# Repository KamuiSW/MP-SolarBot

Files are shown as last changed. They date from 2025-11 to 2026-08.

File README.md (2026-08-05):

# Solar Panel Cleaning Robot

This is the code and hardware files for our 6VWO profielwerkstuk. The project is about a small robot that can map a solar panel, plan a path over it, and detect dirty spots.

## Parts of the project

### 1. Firmware
Language: C++ <br>
Hardware: Raspberry Pi <br><br>
What it does:<br>
Motor control <br>
Edge detection with sensors<br>
Mapping the panel<br>
Navigation over the mapped area<br><br>
Compilation:<br>
    ```g++ main.cpp mapping.cpp navigation.cpp executor.cpp stains.cpp stain_planner.cpp -o robot_core -lwiringPi -std=c++17
    ```

### 2. Web interface and simulation
Backend: Python<br>
Frontend: HTML5<br><br>
The web interface shows the robot position, the path, and detected stains. There is also a Python simulation so we can test the logic without always using the real robot.<br>

## Simulation

1.  Install dependencies:
    ```bash
    pip install fastapi uvicorn websockets
    ```

2.  Run the server:
    ```bash
    python Software\src\Simulation\server.py
    ```

3.  Open the UI:
    Open `http://localhost:8000` in your web browser.

4.  Start the simulation:
Click "Start Simulation".<br>

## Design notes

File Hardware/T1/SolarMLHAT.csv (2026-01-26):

Female pin header 2x20 2.54mm THT vertical
Pin header 1x4 2.54mm THT vertical
Pin header 1x4 2.54mm THT vertical
Pin header 1x3 2.54mm THT vertical
Pin header 1x3 2.54mm THT vertical
Pin header 1x4 2.54mm THT vertical HC-SR04
Pin header 1x4 2.54mm THT vertical HC-SR04
Screw terminal block 2 pin 5.0mm THT
Electrolytic capacitor 2200uF 16V radial 5mm
Ceramic capacitor 100nF 1206 X7R 25V
Resistor 10k ohm 1206 1%
Resistor 10k ohm 1206 1%
Resistor 20k ohm 1206 1%
Resistor 20k ohm 1206 1%

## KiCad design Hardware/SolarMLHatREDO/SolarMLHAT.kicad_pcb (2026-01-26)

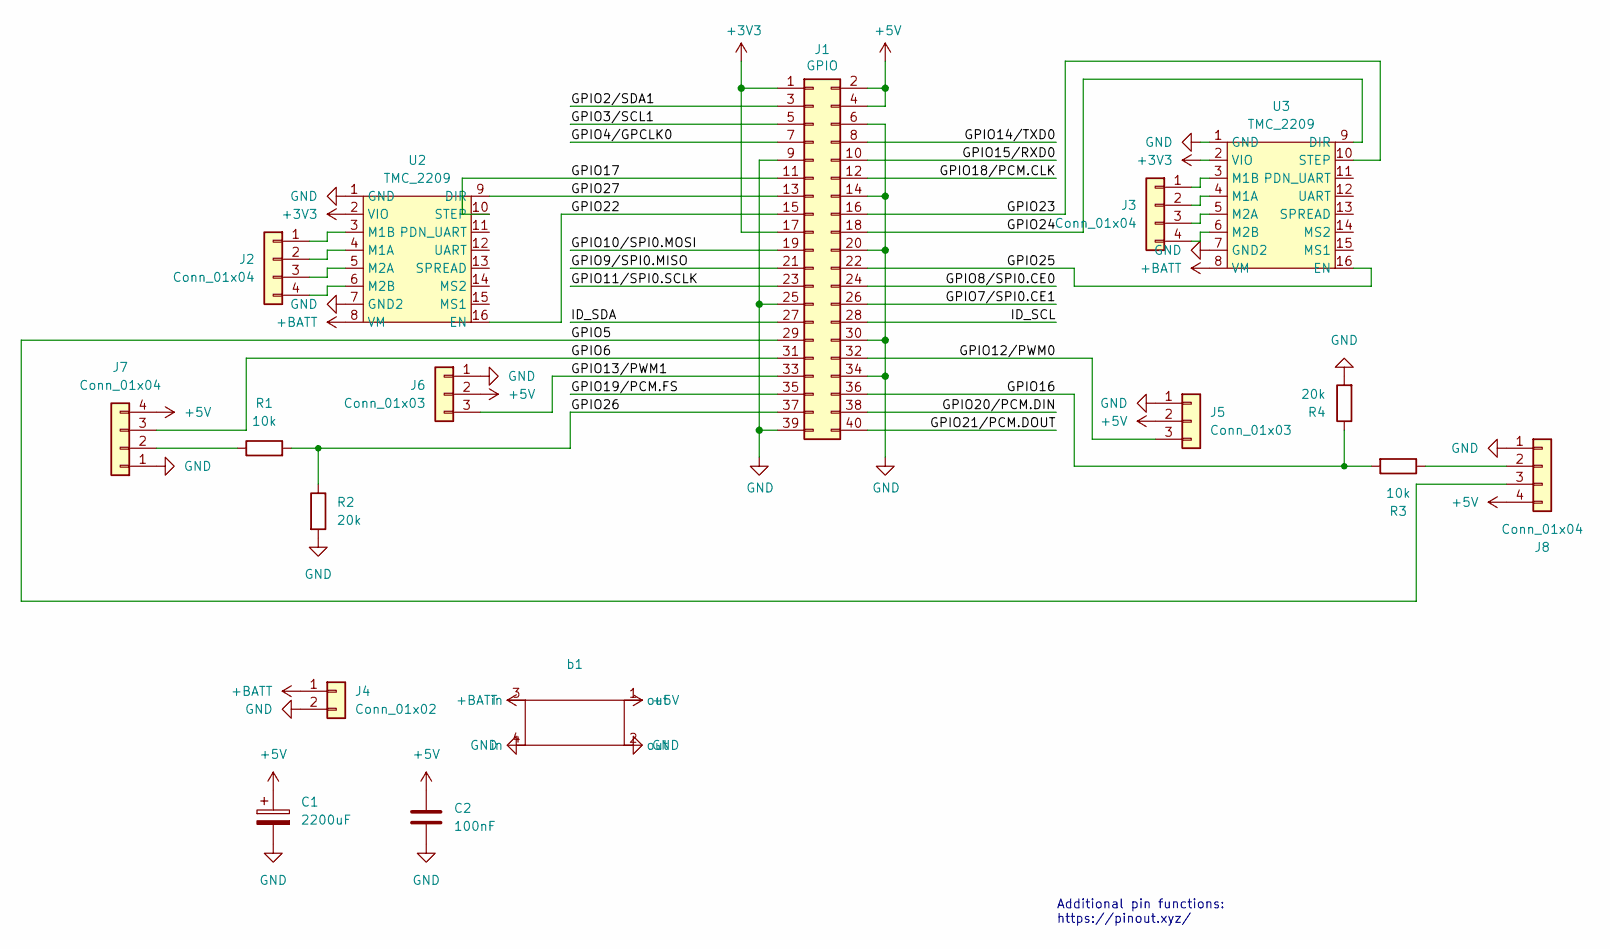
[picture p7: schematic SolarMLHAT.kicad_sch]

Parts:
C1: 2200uF; CP_Radial_D10.0mm_P5.00mm
C2: 100nF; C_1206_3216Metric_Pad1.33x1.80mm_HandSolder
J1: GPIO; PinSocket_2x20_P2.54mm_Vertical
J2, J3: Conn_01x04; JST_PH_B4B-PH-K_1x04_P2.00mm_Vertical
J4: Conn_01x02; TerminalBlock_MaiXu_MX126-5.0-02P_1x02_P5.00mm
J5, J6: Conn_01x03; PinHeader_1x03_P2.54mm_Vertical
J7, J8: Conn_01x04; PinHeader_1x04_P2.54mm_Vertical
R1, R3: 10k; R_1206_3216Metric_Pad1.30x1.75mm_HandSolder
R2, R4: 20k; R_1206_3216Metric_Pad1.30x1.75mm_HandSolder
U2, U3: TMC_2209; TMC_2209_v985
b1: XL4015 5A SizeM

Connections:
+3V3: J1.1, J1.17, U2.2 (VIO), U3.2 (VIO)
+5V: C1.1, C2.1, J1.2, J1.4, J5.2, J6.2, J7.4, J8.4, b1.1 (out)
+BATT: J4.1, U2.8 (VM), U3.8 (VM), b1.3 (in)
/GPIO2/SDA1: J1.3
/GPIO3/SCL1: J1.5
/GPIO4/GPCLK0: J1.7
/GPIO5: J1.29, J8.3
/GPIO6: J1.31, J7.3
/GPIO7/SPI0.CE1: J1.26
/GPIO8/SPI0.CE0: J1.24
/GPIO9/SPI0.MISO: J1.21
/GPIO10/SPI0.MOSI: J1.19
/GPIO11/SPI0.SCLK: J1.23
/GPIO12/PWM0: J1.32, J5.3
/GPIO13/PWM1: J1.33, J6.3
/GPIO14/TXD0: J1.8
/GPIO15/RXD0: J1.10
/GPIO16: J1.36, R3.2, R4.1
/GPIO17: J1.11, U2.10 (STEP)
/GPIO18/PCM.CLK: J1.12
/GPIO19/PCM.FS: J1.35
/GPIO20/PCM.DIN: J1.38
/GPIO21/PCM.DOUT: J1.40
/GPIO22: J1.15, U2.16 (EN)
/GPIO23: J1.16, U3.10 (STEP)
/GPIO24: J1.18, U3.9 (DIR)
/GPIO25: J1.22, U3.16 (EN)
/GPIO26: J1.37, R1.2, R2.1
/GPIO27: J1.13, U2.9 (DIR)
/ID_SCL: J1.28
/ID_SDA: J1.27
GND: C1.2, C2.2, J1.6, J1.9, J1.14, J1.20, J1.25, J1.30, J1.34, J1.39, J4.2, J5.1, J6.1, J7.1, J8.1, R2.2, R4.2, U2.1 (GND), U2.7 (GND2), U3.1 (GND), U3.7 (GND2), b1.2 (out), b1.4 (in)
unnamed: J2.1, U2.3 (M1B)
unnamed: J2.2, U2.4 (M1A)
unnamed: J2.3, U2.5 (M2A)
unnamed: J2.4, U2.6 (M2B)
unnamed: J3.1, U3.3 (M1B)
unnamed: J3.2, U3.4 (M1A)
unnamed: J3.3, U3.5 (M2A)
unnamed: J3.4, U3.6 (M2B)
unnamed: J7.2, R1.1
unnamed: J8.2, R3.1

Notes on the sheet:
Additional pin functions: https://pinout.xyz/

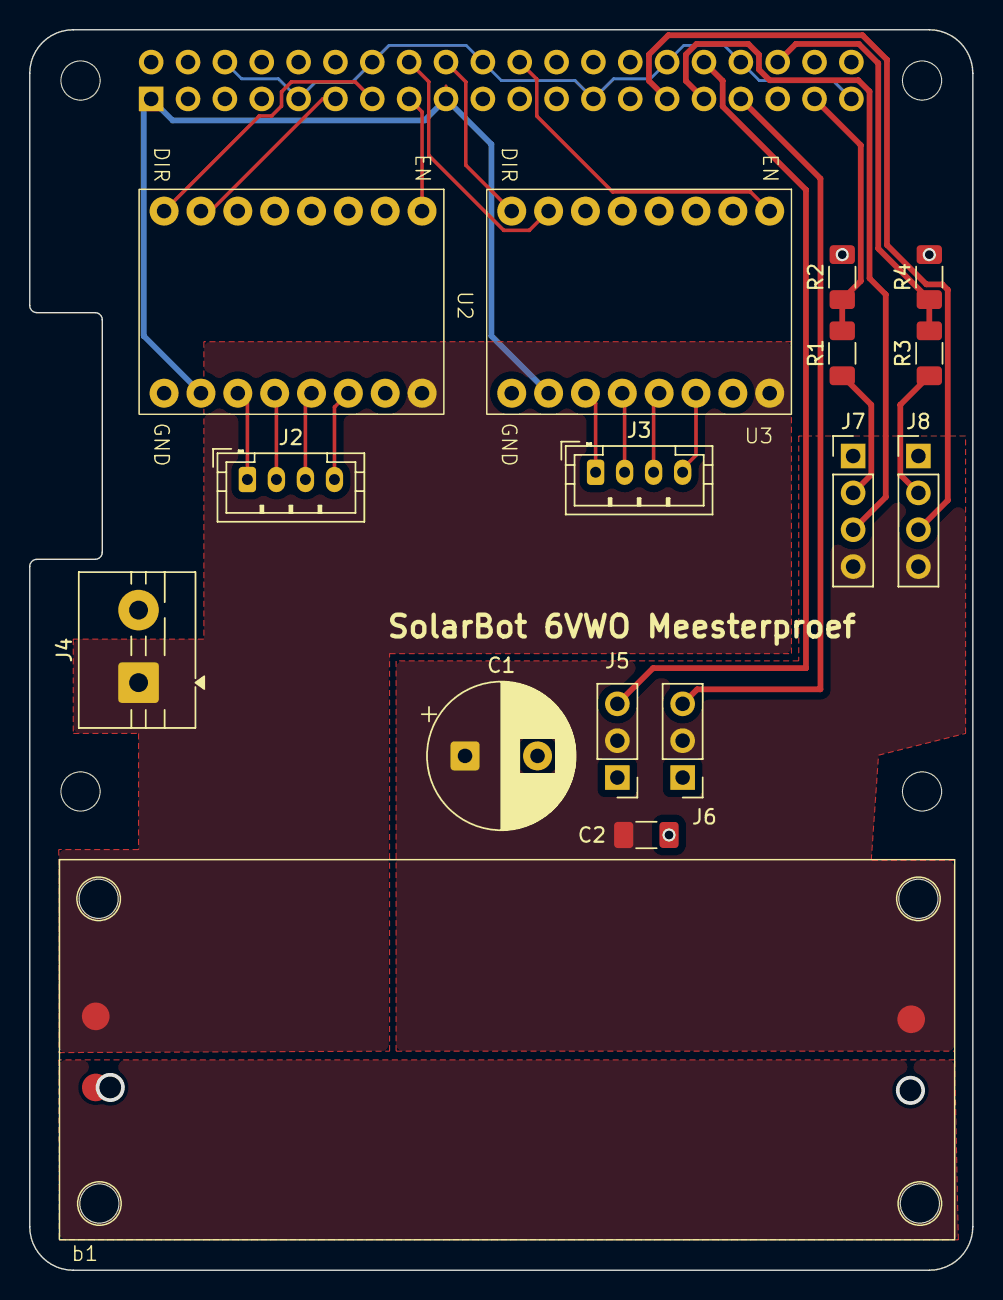
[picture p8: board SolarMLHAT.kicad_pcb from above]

Board: 2 copper layers, 65.0 x 85.5 mm, 21 parts (1 on the bottom side), 26 nets.

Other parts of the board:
MH1, MH2, MH3, MH4: MountingHole_2.7mm_M2.5

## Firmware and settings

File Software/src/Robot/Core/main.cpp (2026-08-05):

#include <atomic>
#include <iostream>
#include <string>
#include <thread>
#include <vector>

#include "config.h"
#include "executor.h"
#include "mapping.h"
#include "navigation.h"

// The Python server sends one JSON command per line, for example:
// {"cmd": "start_mapping"}

void printJsonStatus(const std::string &status, const std::string &msg = "") {
  std::cout << "{\"type\":\"status\", \"status\": \"" << status
            << "\", \"msg\": \"" << msg << "\"}" << std::endl;
}

int main() {
  printJsonStatus("IDLE", "Robot Core Ready");

  std::string line;
  while (std::getline(std::cin, line)) {
    if (line.find("start_mapping") != std::string::npos) {
      printJsonStatus("BUSY", "Starting Mapping...");
      if (runMapping()) {
        printJsonStatus("IDLE", "Mapping Complete");
      } else {
        printJsonStatus("ERROR", "Mapping Failed");
      }
    } else if (line.find("start_navigation") != std::string::npos) {
      printJsonStatus("BUSY", "Starting Navigation...");
      if (runNavigation()) {
        printJsonStatus("IDLE", "Navigation Planning Complete");
      } else {
        printJsonStatus("ERROR", "Navigation Planning Failed");
      }
    } else if (line.find("start_execution") != std::string::npos) {
      printJsonStatus("BUSY", "Starting Execution...");
      if (runExecuteNavigation()) {
        printJsonStatus("IDLE", "Execution Complete");
      } else {
        printJsonStatus("ERROR", "Execution Failed");
      }
      printJsonStatus("ERROR", "Execution Failed");
    }
  }
  else if (line.find("stop") != std::string::npos) {
    printJsonStatus("STOPPED", "Stopping...");
    // For now stop just exits the loop.
    break;
  }
}

return 0;
}

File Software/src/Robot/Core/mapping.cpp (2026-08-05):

#ifndef MOCK_HARDWARE
#include <wiringPi.h>
#endif

#include <algorithm>
#include <chrono>
#include <fstream>
#include <iostream>
#include <set>
#include <thread>
#include <vector>

#include "config.h"
#include "mapping.h"

class Stepper {
public:
  int stepPin, dirPin, enPin;
  bool forwardLevel;

  Stepper(int step, int dir, int en, bool fwdLevel)
      : stepPin(step), dirPin(dir), enPin(en), forwardLevel(fwdLevel) {}

  void begin() {
    pinMode(stepPin, OUTPUT);
    pinMode(dirPin, OUTPUT);
    pinMode(enPin, OUTPUT);
    digitalWrite(enPin, LOW);
    digitalWrite(stepPin, LOW);
    digitalWrite(dirPin, forwardLevel ? HIGH : LOW);
  }

  void enable(bool on) { digitalWrite(enPin, on ? LOW : HIGH); }

  void setForward(bool forward) {
    bool lvl = forward ? forwardLevel : !forwardLevel;
    digitalWrite(dirPin, lvl ? HIGH : LOW);
  }

  void stepOnce() {
    digitalWrite(stepPin, HIGH);
    delayMicroseconds(STEP_PULSE_US);
    digitalWrite(stepPin, LOW);
  }
};

class DifferentialDrive {
public:
  Stepper left;
  Stepper right;

  DifferentialDrive(Stepper l, Stepper r) : left(l), right(r) {}

  void begin() {
    left.begin();
    right.begin();
    left.enable(true);
    right.enable(true);
  }

  void stop() {
    left.enable(false);
    right.enable(false);
  }

  void forwardCell() {
    left.setForward(true);
    right.setForward(true);
    for (int i = 0; i < STEPS_PER_CELL; i++) {
      left.stepOnce();
      right.stepOnce();
      delayMicroseconds(STEP_DELAY_US);
    }
  }

  void turnRight90() {
    left.setForward(true);
    right.setForward(false);
    for (int i = 0; i < STEPS_PER_90_TURN; i++) {
      left.stepOnce();
      right.stepOnce();
      delayMicroseconds(STEP_DELAY_US);
    }
  }

  void turnLeft90() {
    left.setForward(false);
    right.setForward(true);
    for (int i = 0; i < STEPS_PER_90_TURN; i++) {
      left.stepOnce();
      right.stepOnce();
      delayMicroseconds(STEP_DELAY_US);
    }
  }
};

enum class Direction { UP = 0, RIGHT = 1, DOWN = 2, LEFT = 3 };

static const char *dirName(Direction d) {
  switch (d) {
  case Direction::UP:
    return "UP";
  case Direction::RIGHT:
    return "RIGHT";
  case Direction::DOWN:
    return "DOWN";
  case Direction::LEFT:
    return "LEFT";
  }
  return "?";
}

struct Pose {
  int x = 0, y = 0;
  Direction dir = Direction::UP;
};

static void stepForward(Pose &p) {
  switch (p.dir) {
  case Direction::UP:
    p.y += 1;
    break;
  case Direction::DOWN:
    p.y -= 1;
    break;
  case Direction::LEFT:
    p.x -= 1;
    break;
  case Direction::RIGHT:
    p.x += 1;
    break;
  }
}

static void turnRight(Pose &p) {
  p.dir = static_cast<Direction>((static_cast<int>(p.dir) + 1) % 4);
}

static void turnLeft(Pose &p) {
  p.dir = static_cast<Direction>((static_cast<int>(p.dir) + 3) % 4);
}

class Ultrasonic {
public:
  int trigPin;
  int echoPin;

  Ultrasonic(int trig, int echo) : trigPin(trig), echoPin(echo) {}

  void begin() {
    pinMode(trigPin, OUTPUT);
    pinMode(echoPin, INPUT);
    digitalWrite(trigPin, LOW);
    delay(50);
  }

  float readDistanceCm(float timeoutSeconds = 0.03f) {
    digitalWrite(trigPin, LOW);
    delayMicroseconds(2);
    digitalWrite(trigPin, HIGH);
    delayMicroseconds(10);
    digitalWrite(trigPin, LOW);

    auto start = std::chrono::high_resolution_clock::now();
    while (digitalRead(echoPin) == LOW) {
      auto now = std::chrono::high_resolution_clock::now();
      std::chrono::duration<float> elapsed = now - start;
      if (elapsed.count() > timeoutSeconds)
        return 999.0f;
    }

    auto pulseStart = std::chrono::high_resolution_clock::now();
    while (digitalRead(echoPin) == HIGH) {
      auto now = std::chrono::high_resolution_clock::now();
      std::chrono::duration<float> elapsed = now - pulseStart;
      if (elapsed.count() > timeoutSeconds)
        return 999.0f;
    }

    auto pulseEnd = std::chrono::high_resolution_clock::now();
    std::chrono::duration<float> pulseDuration = pulseEnd - pulseStart;
    float seconds = pulseDuration.count();
    return (seconds * 34300.0f) / 2.0f;
  }

  bool isCliffRaw() {
    float d = readDistanceCm();
    if (d <= 0 || d > 900.0f)
      return true;
    return d > CLIFF_THRESHOLD_CM;
  }
};

struct CliffSensors {
  bool frontCliff = false;
  bool leftCliff = false;
};

// Take multiple readings so one bad sensor value does not break the map.
static bool filteredIsCliff(Ultrasonic &s, int samples = 5,
                            int votesRequired = 3) {
  int votes = 0;
  for (int i = 0; i < samples; i++) {
    if (s.isCliffRaw())
      votes++;
    delay(8);
  }
  return votes >= votesRequired;
}

static CliffSensors readCliffSensorsFiltered(Ultrasonic &front,
                                             Ultrasonic &left) {
  CliffSensors cs;
  cs.frontCliff = filteredIsCliff(front, 5, 3);
  cs.leftCliff = filteredIsCliff(left, 5, 3);
  return cs;
}
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

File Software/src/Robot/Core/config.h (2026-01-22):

constexpr double ROBOT_WIDTH_CM = 28.0;
constexpr double ROBOT_LENGTH_CM = 32.0;
constexpr double CELL_SIZE_CM = 5.0;

constexpr double CLIFF_THRESHOLD_CM = 30.0;

constexpr int TRIG_FRONT = 2;
constexpr int ECHO_FRONT = 3;

constexpr int TRIG_LEFT = 27;
constexpr int ECHO_LEFT = 22;

constexpr int L_STEP = 21;
constexpr int L_DIR = 20;
constexpr int L_EN = 16;

constexpr int R_STEP = 13;
constexpr int R_DIR = 19;
constexpr int R_EN = 26;

constexpr bool L_DIR_FORWARD_LEVEL = true;
constexpr bool R_DIR_FORWARD_LEVEL = true;

constexpr int STEPS_PER_CELL = 800;
constexpr int STEPS_PER_90_TURN = 600;

constexpr int STEP_PULSE_US = 3;
constexpr int STEP_DELAY_US = 700;

constexpr const char *MAP_JSON_PATH = "map.json";
constexpr const char *NAVIGATION_JSON_PATH = "navigation.json";

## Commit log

2025-12-20 Heatmap_demo change image
2026-01-26 Add SolarMLHAT PCB design files and assets
    Initial commit of SolarMLHAT hardware design files, including KiCad project files, Gerber outputs, fabrication data, and design backups. Also adds a new asset to the simulation software.
    [SolarMLHAT-B_Cu.gbl, SolarMLHAT-B_Mask.gbs, SolarMLHAT-B_Silkscreen.gbo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]
2026-07-29 heatmap modifications
